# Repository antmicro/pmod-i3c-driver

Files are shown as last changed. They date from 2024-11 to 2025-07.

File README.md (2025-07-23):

# PMOD I3C Driver

Copyright (c) 2024 [Antmicro](https://www.antmicro.com)

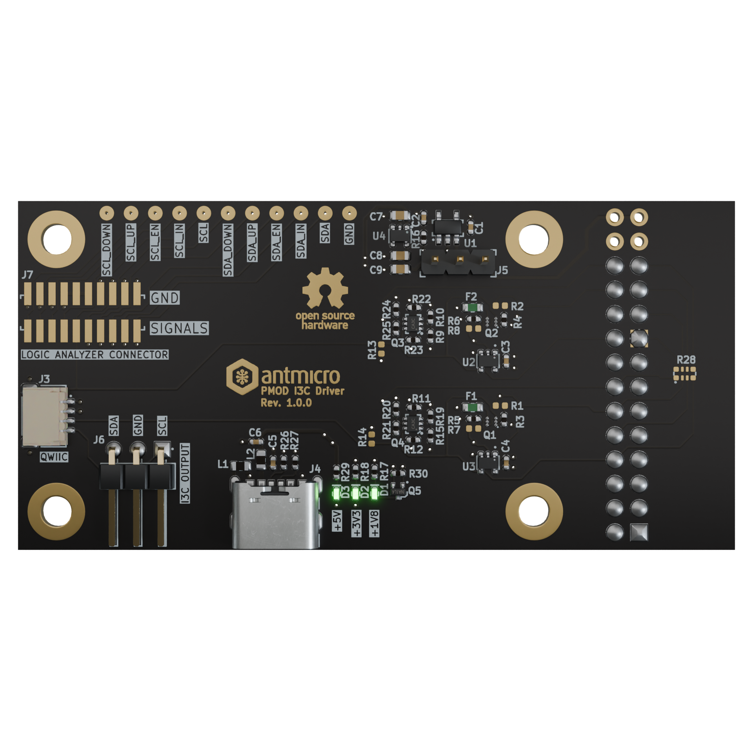
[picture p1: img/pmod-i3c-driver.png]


## Overview

This project contains open hardware design files for a simple expansion PCB with two push-pull digital output drivers composed of discrete MOSFETs.
This allows to use the board with FPGA-driven systems to implement I3C output stage driver which can act as open drain or push-pull. 
The driver topology is switchable via digital control signals from FPGA-side.
A separate set of control signals allows to activate pull-up or pull-down resistors connected to the output signals.
The design files were prepared in KiCad 9.x.

## Key features

* Two independent digital output stages configurable as push-pull or open drain
* Switchable pull-up and pull-down resistors
* The board is compatible with PMOD (3.3V logic) expansion connector 
* The board is compatible with a 24-pin proto header (J3) available on AMD (Xilinx) [ZCU106 Evaluation Kit](https://www.xilinx.com/products/boards-and-kits/zcu106.html) 

## Project structure

The main directory contains KiCad PCB project files, a LICENSE, and a README.
The remaining files are stored in the following directories: 

* `img` - contains graphics for this README 
* `doc` - contains board schematic in PDF format

## Licensing

This project is published under the [Apache-2.0](LICENSE) license.

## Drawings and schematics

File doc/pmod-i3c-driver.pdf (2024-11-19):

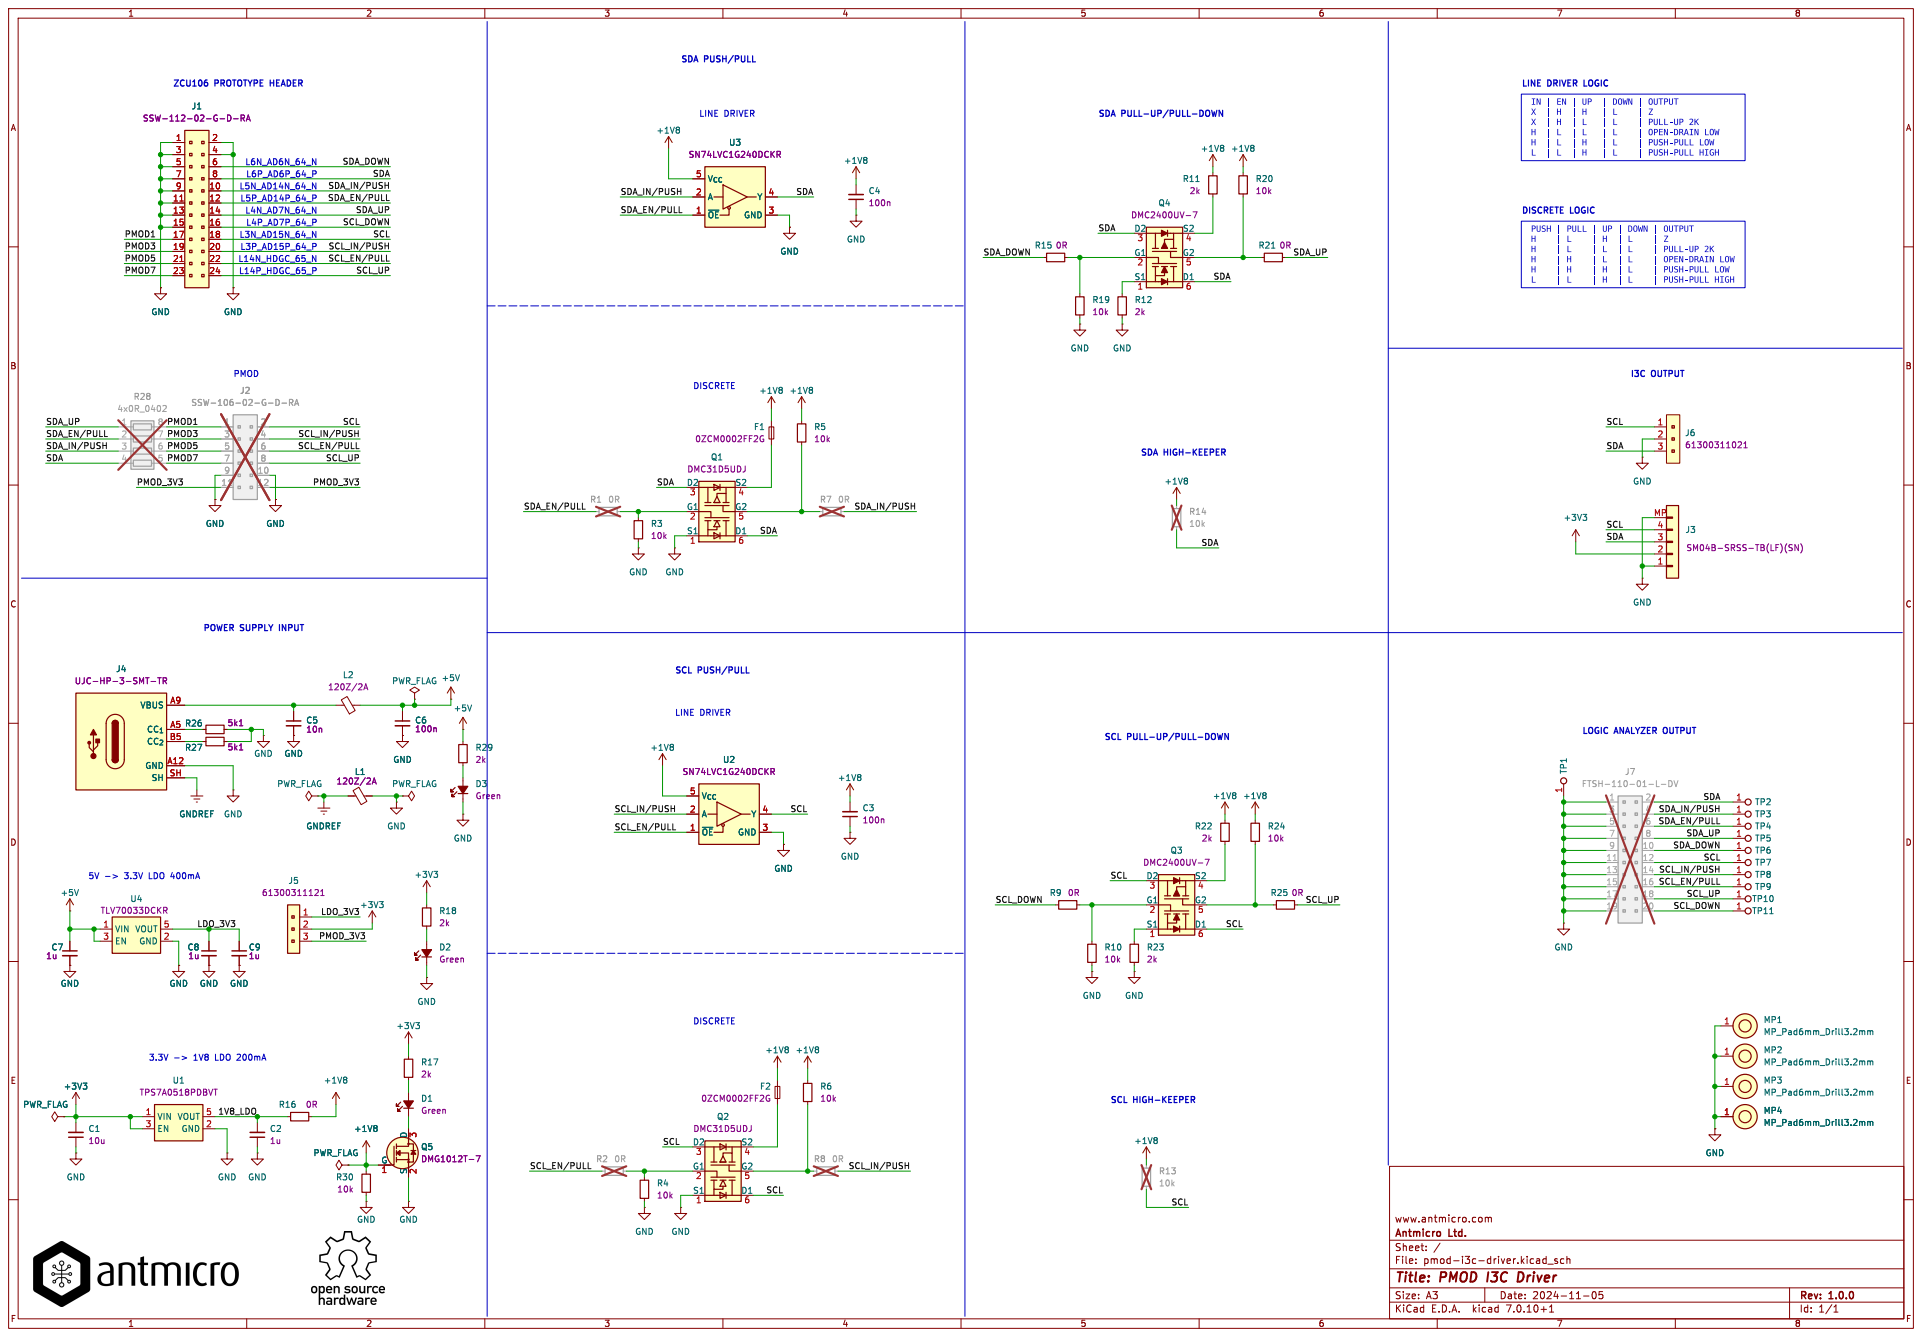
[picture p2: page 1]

SDA PULL-UP/PULL-DOWN

SCL PUSH/PULL PMOD

J3SM04B-SRSS-TB(LF)(SN) R9 0R

J4 UJC-HP-3-SMT-TR

SCL PULL-UP/PULL-DOWN

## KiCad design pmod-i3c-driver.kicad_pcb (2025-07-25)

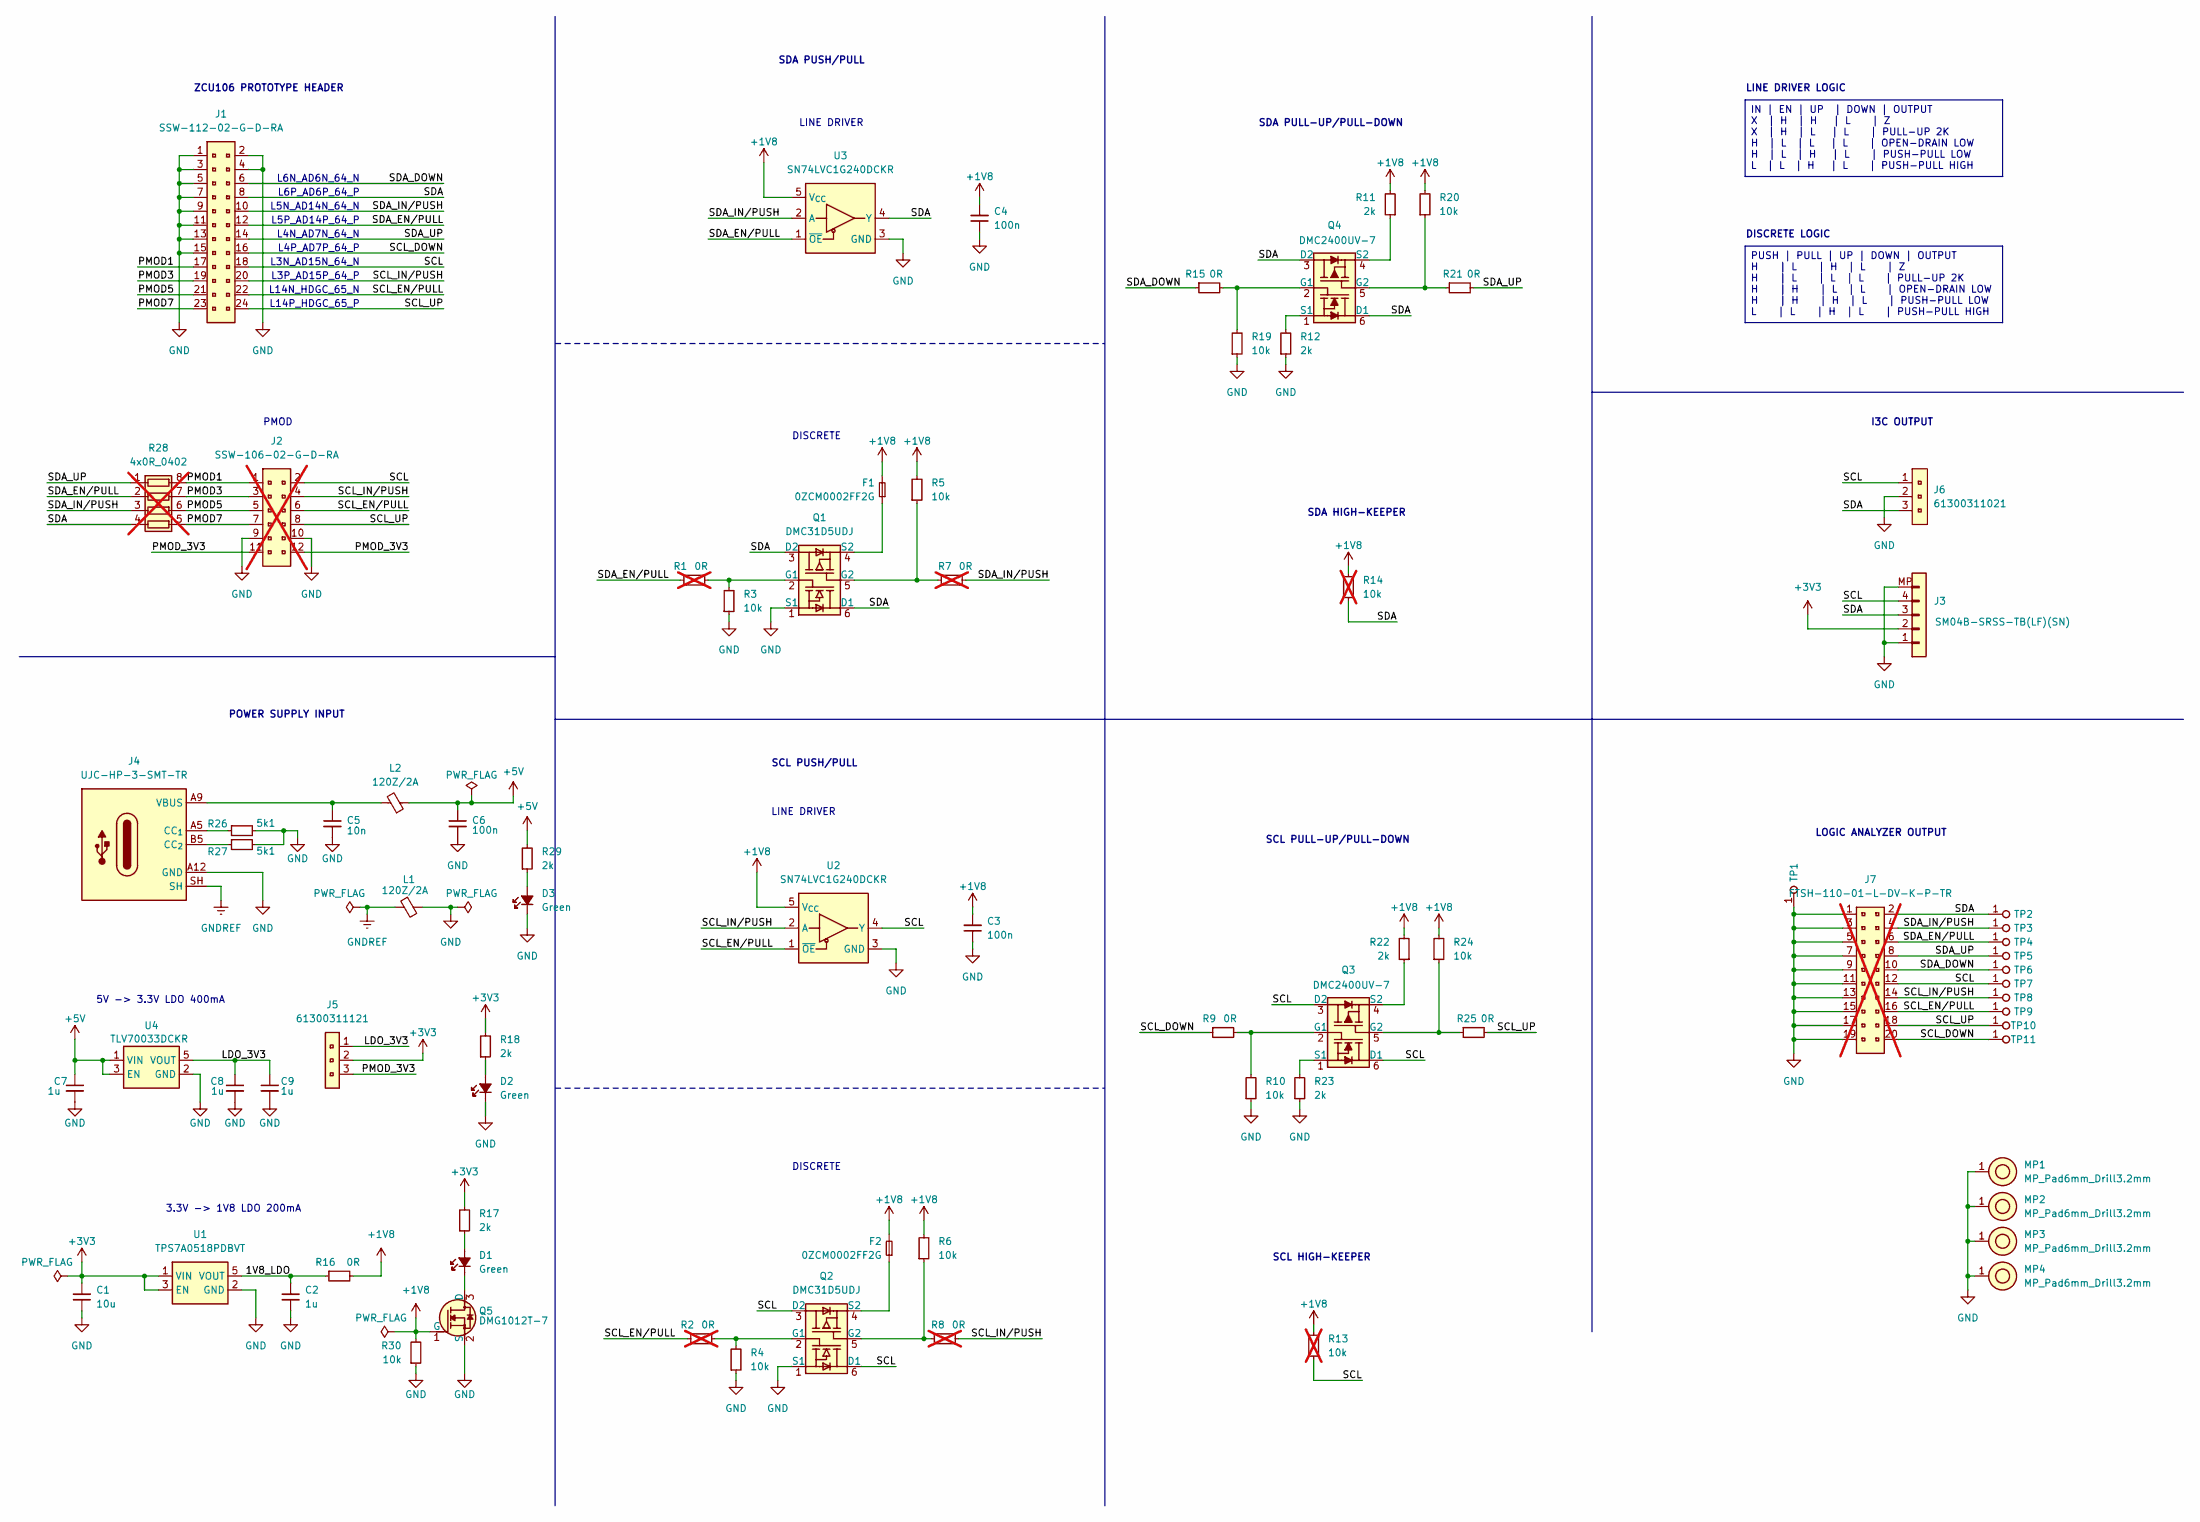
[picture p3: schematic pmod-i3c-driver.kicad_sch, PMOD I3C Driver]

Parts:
C1: C_10u_0402; C_0402_1005Metric; MPN CC0402MRX5R5BB106
C2: C_1u_0402; C_0402_1005Metric; MPN C1005X6S1A105K050BC
C3, C4: C_100n_0402; C_0402_1005Metric; Voltage 50V; MPN GRM155R61H104KE14D
C5: C_10n_0402; C_0402_1005Metric; Voltage 50V; MPN GRM155R71H103KA88D
C6: C_100n_16V_X7R_0402; C_0402_1005Metric; Voltage 16V; MPN C0402C104J4RAC7411
C7, C8, C9: C_1u_0603; C_0603_1608Metric; MPN 0603YD105KAT2A
D1, D2, D3: LED_G_0402_VLMTG1500-GS08; LED_0402_1005Metric_G; MPN VLMTG1500-GS08
F1, F2: F_20mA_0603; F_0603_1608Metric; MPN 0ZCM0002FF2G
J1: PinSocket_2x12_P2.54mm_Drill1.04mm_Horizontal; MPN SSW-112-02-G-D-RA
J2: PinSocket_2x6_P2.54mm_Drill1.04mm_Horizontal; MPN SSW-106-02-G-D-RA; not fitted
J3: JST_SH_1x4_SM04B-SRSS-TB-LF-SN; Conn_JST_SH_1x4_SM04B-SRSS-TB-LF-SN; MPN SM04B-SRSS-TB(LF)(SN)
J4: USB-C_CUI_UJC-HP-3-SMT-TR; USB-C_Receptacle_CUI_UJC-HP-3-SMT-TR; MPN UJC-HP-3-SMT-TR
J5: PinHeader_1x3_P2.54mm_Drill1.1mm; MPN 61300311121
J6: PinHeader_1x3_P2.54mm_Drill1.1mm_Horizontal; PinHeader_1x3_P2.54mm_Horizontal; MPN 61300311021
J7: PinHeader_2x10_P1.27mm_SMD_Latch; MPN FTSH-110-01-L-DV-K-P-TR; not fitted
L1, L2: FB_120Z_2A_Murata-BLM18PG_0603; FB_0603_1608Metric; MPN BLM18PG121SN1D
MP1, MP2, MP3, MP4: MP_Pad6mm_Drill3.2mm
Q1, Q2: DMC31D5UDJ; SOT-963; MPN DMC31D5UDJ
Q3, Q4: DMC2400UV-7; SOT-563; MPN DMC2400UV-7
Q5: DMG1012T-7; SOT-523; MPN DMG1012T-7
R1, R2, R7, R8: R_0R_0402; R_0402_1005Metric; MPN ERJ2GE0R00X; not fitted
R3, R4, R5, R6, R10, R19, R20, R24, R30: R_10k_0402; R_0402_1005Metric; Tolerance 1%; MPN CR0402-FX-1002GLF
R9, R15, R16, R21, R25: R_0R_0402; R_0402_1005Metric; MPN ERJ2GE0R00X
R11, R12, R17, R18, R22, R23, R29: R_2k_0402; R_0402_1005Metric; Tolerance 1%; MPN CR0402-FX-2001GLF
R13, R14: R_10k_0402; R_0402_1005Metric; Tolerance 1%; MPN CR0402-FX-1002GLF; not fitted
R26, R27: R_5k1_0402; R_0402_1005Metric; Tolerance 1%; MPN CR0402-FX-5101GLF
R28: 4x0R_0402_array; 4x0R_0402_array_EXB28V; MPN EXB28VR000X; not fitted
TP1, TP2, TP3, TP4, TP5, TP6, TP7, TP8, TP9, TP10, TP11: TP_1.5mm_SMD; TP_SMD_1.5mm
U1: TPS7A0518P_SOT23-5; SOT-23-5; MPN TPS7A0518PDBVT
U2, U3: SN74LVC1G240_SC70; SOT-353; MPN SN74LVC1G240DCKR
U4: TLV70033_SC70; SC-70-5; MPN TLV70033DCKR

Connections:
+1V8: C3.2, C4.2, F1.2, F2.2, Q5.1 (G), R5.2, R6.2, R11.2, R13.2, R14.2, R16.2, R20.2, R22.2, R24.2, R30.2, U2.5 (V_{CC}), U3.5 (V_{CC})
+3V3: C1.2, J3.2, J5.2, R17.2, R18.2, U1.1 (VIN), U1.3 (EN)
+5V: C6.1, C7.1, L2.1, R29.2, U4.1 (VIN), U4.3 (EN)
/1V8_LDO: C2.2, R16.1, U1.5 (VOUT)
/LDO_3V3: C8.1, C9.1, J5.1, U4.5 (VOUT)
/PMOD1: J1.17, J2.1, R28.8 (R1.2)
/PMOD3: J1.19, J2.3, R28.7 (R2.2)
/PMOD5: J1.21, J2.5, R28.6 (R3.2)
/PMOD7: J1.23, J2.7, R28.5 (R4.2)
/PMOD_3V3: J2.11, J2.12, J5.3
/SCL: J1.18, J2.2, J3.4, J6.1, J7.12, Q2.3 (D2), Q2.6 (D1), Q3.3 (D2), Q3.6 (D1), R13.1, TP7.1, U2.4 (Y)
/SCL_DOWN: J1.16, J7.20, R9.1, TP11.1
/SCL_EN/PULL: J1.22, J2.6, J7.16, R2.1, TP9.1, U2.1 (~OE)
/SCL_IN/PUSH: J1.20, J2.4, J7.14, R8.2, TP8.1, U2.2 (A)
/SCL_UP: J1.24, J2.8, J7.18, R25.2, TP10.1
/SDA: J1.8, J3.3, J6.3, J7.2, Q1.3 (D2), Q1.6 (D1), Q4.3 (D2), Q4.6 (D1), R14.1, R28.4 (R4.1), TP2.1, U3.4 (Y)
/SDA_DOWN: J1.6, J7.10, R15.1, TP6.1
/SDA_EN/PULL: J1.12, J7.6, R1.1, R28.2 (R2.1), TP4.1, U3.1 (~OE)
/SDA_IN/PUSH: J1.10, J7.4, R7.2, R28.3 (R3.1), TP3.1, U3.2 (A)
/SDA_UP: J1.14, J7.8, R21.2, R28.1 (R1.1), TP5.1
GND: C1.1, C2.1, C3.1, C4.1, C5.2, C6.2, C7.2, C8.2, C9.2, D2.1 (C), D3.1 (C), J1.1, J1.2, J1.3, J1.4, J1.5, J1.7, J1.9, J1.11, J1.13, J1.15, J2.9, J2.10, J3.1, J3.MP, J4.A12 (GND), J4.B12 (GND), J6.2, J7.1, J7.3, J7.5, J7.7, J7.9, J7.11, J7.13, J7.15, J7.17, J7.19, L1.2, MP1.1, MP2.1, MP3.1, MP4.1, Q1.1 (S1), Q2.1 (S1), Q5.2 (S), R3.1, R4.1, R10.1, R12.1, R19.1, R23.1, R26.2, R27.2, R30.1, TP1.1, U1.2 (GND), U2.3 (GND), U3.3 (GND), U4.2 (GND)
GNDREF: J4.SH, L1.1
unnamed: C5.1, J4.A9 (VBUS), J4.B9 (VBUS), L2.2
unnamed: D1.2 (A), R17.1
unnamed: D1.1 (C), Q5.3 (D)
unnamed: D2.2 (A), R18.1
unnamed: D3.2 (A), R29.1
unnamed: J4.A5 (CC_{1}), R26.1
unnamed: J4.B5 (CC_{2}), R27.1
unnamed: Q1.2 (G1), R1.2, R3.2
unnamed: Q1.5 (G2), R5.1, R7.1
unnamed: F1.1, Q1.4 (S2)
unnamed: Q2.2 (G1), R2.2, R4.2
unnamed: Q2.5 (G2), R6.1, R8.1
unnamed: F2.1, Q2.4 (S2)
unnamed: Q3.2 (G1), R9.2, R10.2
unnamed: Q3.5 (G2), R24.1, R25.1
unnamed: Q3.1 (S1), R23.2
unnamed: Q3.4 (S2), R22.1
unnamed: Q4.2 (G1), R15.2, R19.2
unnamed: Q4.5 (G2), R20.1, R21.1
unnamed: Q4.1 (S1), R12.2
unnamed: Q4.4 (S2), R11.1

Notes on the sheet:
LINE DRIVER
L4N_AD7N_64_N
DISCRETE
L3N_AD15N_64_N
DISCRETE LOGIC
LINE DRIVER LOGIC
L6P_AD6P_64_P
SCL PUSH/PULL
L14N_HDGC_65_N
SDA PUSH/PULL
5V -> 3.3V LDO 400mA
LOGIC ANALYZER OUTPUT
L6N_AD6N_64_N
L5N_AD14N_64_N
SDA HIGH-KEEPER
L4P_AD7P_64_P
L5P_AD14P_64_P
PMOD
SCL PULL-UP/PULL-DOWN
ZCU106 PROTOTYPE HEADER
SCL HIGH-KEEPER
I3C OUTPUT
L3P_AD15P_64_P
L14P_HDGC_65_P
SDA PULL-UP/PULL-DOWN
POWER SUPPLY INPUT
3.3V -> 1V8 LDO 200mA
IN | EN | UP | DOWN | OUTPUT X | H | H | L | Z X | H | L | L | PULL-UP 2K H | L | L | L | OPEN-DRAIN LOW H | L | H | L | PUSH-PULL LOW L | L | H | L | PUSH-PULL HIGH
PUSH | PULL | UP | DOWN | OUTPUT H | L | H | L | Z H | L | L | L | PULL-UP 2K H | H | L | L | OPEN-DRAIN LOW H | H | H | L | PUSH-PULL LOW L | L | H | L | PUSH-PULL HIGH

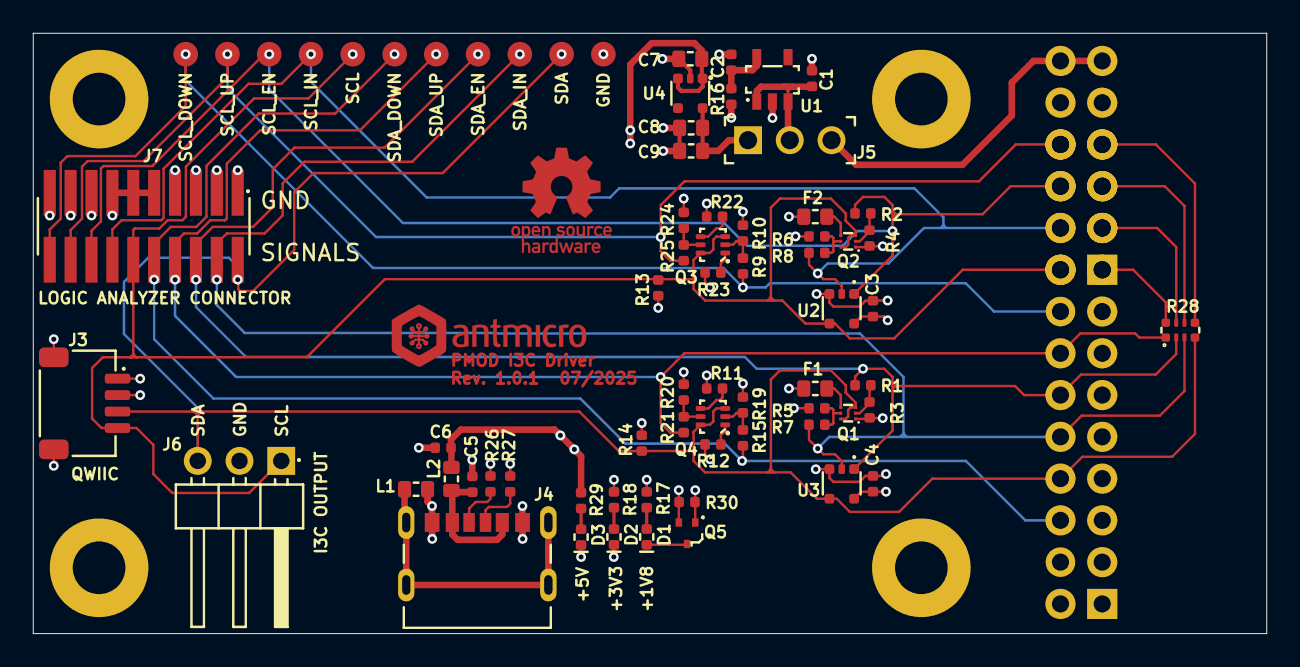
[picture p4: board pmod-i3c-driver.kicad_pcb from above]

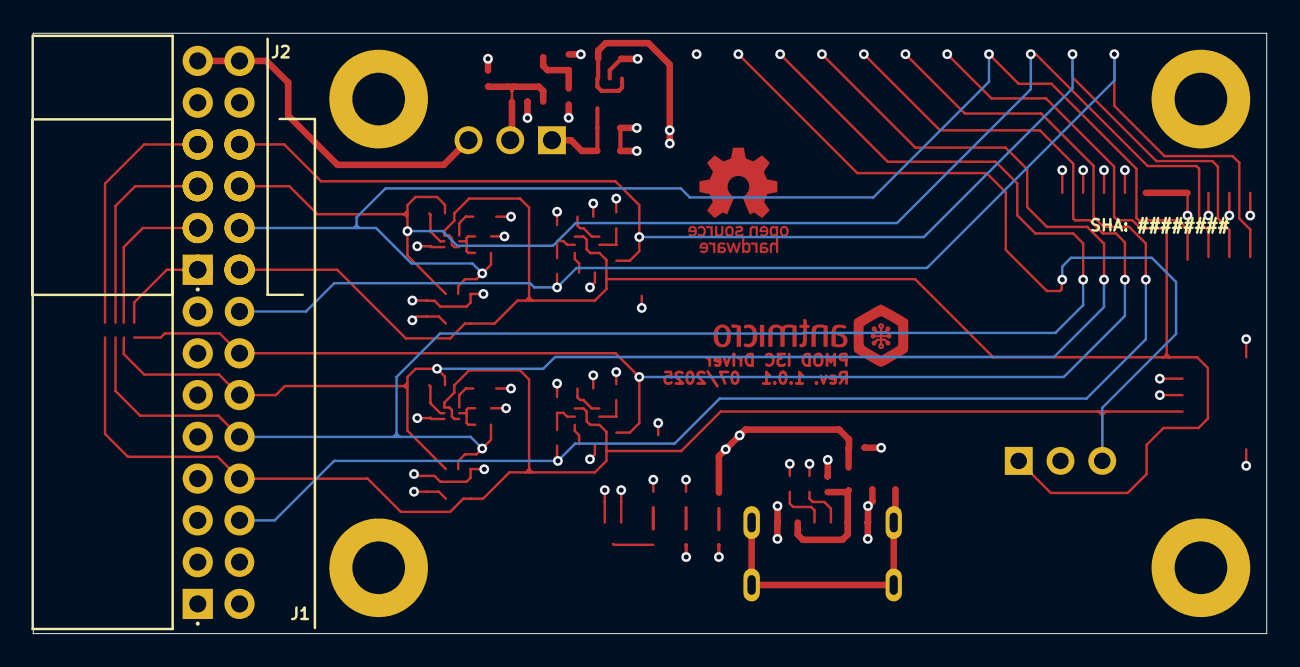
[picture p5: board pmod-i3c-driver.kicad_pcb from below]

Board: 4 copper layers, 75.0 x 36.5 mm, 77 parts (2 on the bottom side), 43 nets.

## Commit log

2024-11-11 [#68164] Add schematic and PCB
    [i3c_output_stage_adapter.kicad_pcb, i3c_output_stage_adapter.kicad_sch]
2024-11-11 [#68164] Update schematic
    [i3c_output_stage_adapter.kicad_sch]
2024-11-11 [#68164] Populate resistors
    [i3c_output_stage_adapter.kicad_sch]
2024-11-11 [#68164] Clean ERC
    [i3c_output_stage_adapter.kicad_sch]
2024-11-11 [#68164] Clean DRC
    [i3c_output_stage_adapter.kicad_pcb, i3c_output_stage_adapter.kicad_sch]
2024-11-11 [#68164] Update PMOS connections on schematic
    [i3c_output_stage_adapter.kicad_sch]
2024-11-11 [#68164] Update PMOS connections on PCB
    [i3c_output_stage_adapter.kicad_pcb]
2024-11-11 [#68164] Add logos, align mounting holes
    [i3c_output_stage_adapter.kicad_pcb, i3c_output_stage_adapter.kicad_sch]
2024-11-11 [#68164] Update power supply, input and output connectors
    [i3c_output_stage_adapter.kicad_sch]
2024-11-11 [#68164] Apply changes to PCB
    [i3c_output_stage_adapter.kicad_pcb]
2024-11-11 [#68164] Update components, rotate PCB
    [i3c_output_stage_adapter.kicad_pcb, i3c_output_stage_adapter.kicad_sch]
2024-11-11 Update naming convention
    [pmod-i3c-driver.kicad_pcb, pmod-i3c-driver.kicad_sch]
2024-11-11 Make J7 DNP
    [pmod-i3c-driver.kicad_pcb, pmod-i3c-driver.kicad_sch]
2024-11-12 Add PDF schematic
2024-11-19 Use monospace font for schematic
    [pmod-i3c-driver.kicad_sch]
2025-07-21 [#80692] Bump design to KiCad 9.0
    [pmod-i3c-driver.kicad_pcb, pmod-i3c-driver.kicad_sch]
2025-07-22 [#80692] Fix DNP
    [pmod-i3c-driver.kicad_pcb, pmod-i3c-driver.kicad_sch]
2025-07-22 [#80692] Update symbols, fix ERC
    [pmod-i3c-driver.kicad_sch]
2025-07-22 [#80692] Update footprints, clean ERC, bump rev to 1.0.1
    [pmod-i3c-driver.kicad_pcb, pmod-i3c-driver.kicad_sch]
2025-07-23 [#80692] README: Update KiCad version
2025-07-25 [#80692] Update silkscreen and DNP
    [pmod-i3c-driver.kicad_pcb]

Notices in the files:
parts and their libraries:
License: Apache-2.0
